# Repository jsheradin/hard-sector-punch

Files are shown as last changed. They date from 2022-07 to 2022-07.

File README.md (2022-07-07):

# hard-sector-punch

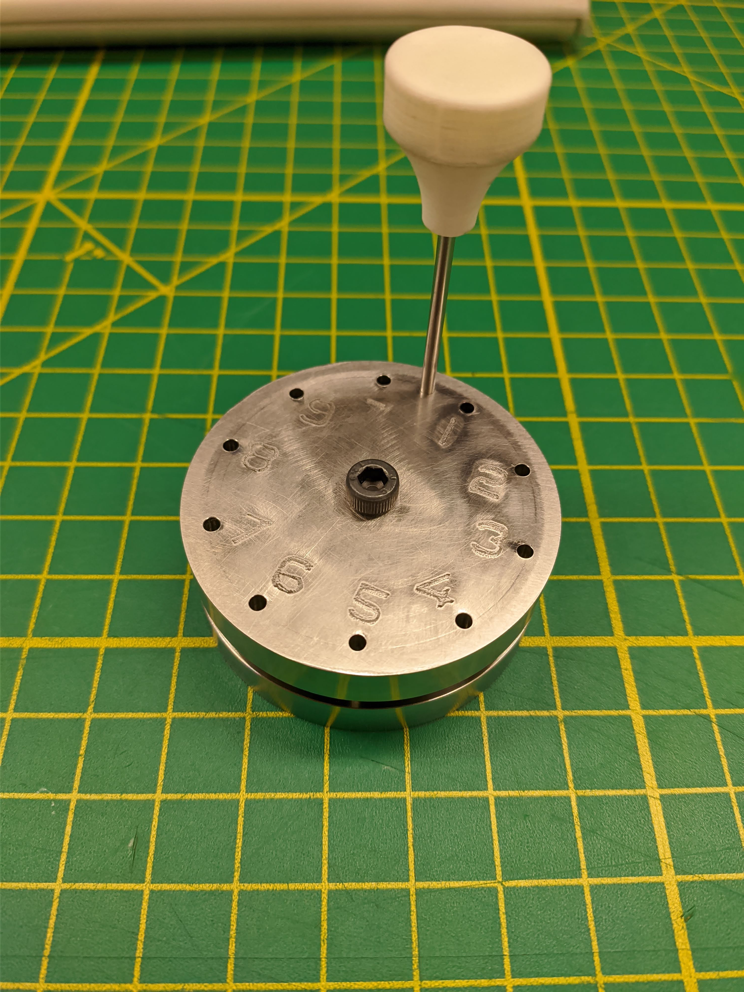
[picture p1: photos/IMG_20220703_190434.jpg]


## Purpose
Some older computers require hard-sector floppies. These differ from the more common soft-sector floppies in that there are additional holes to physically mark the beginning of each sector. Both soft-sector and hard-sector floppies have a hole to mark the start of rotation. Soft-sector floppies can be converted to hard-sector by punching the additional required holes.

## Floppy considerations
### Floppy size
Hard-sector formats were used in both 5.25" and 8" formats. The punches here are designed for use with 5.25" disks. I don't have any 8" disks on hand to check alignment.

### Coercivity
Most drives that used hard sector expect 300 Oe coercivity and won't be able to magnetize disks with higher coercivity. High-density (HD) floppies will most likely not work. The older double-density (DD) floppies likely will.

### Sector count
Not all hard-sector floppies are the same sector count. Usually a computer is only compatible with a specific configuration. 10 and 16 sectors were both commonly used in 5.25" format. 8" disks often had even more. The correct punch must be used to match the target machine.

### Single/double sided
Double-sided (DS) floppies will work for both double and single-sided drives. Single-sided (SS) floppies will work only in single-sided drives.

## Files
Provided are CAD files in various formats for a 10 sector 5.25" punch. They have been tested to work both as 3D printed PLA and CNC'd stainless steel. These were designed in Autodesk Inventor which uses ipt files. The exported stp files should be compatible with nearly all programs.

## Reaming
It's recommended to ream the punch holes to ensure as close of a fit as possible to the punch pin. McMaster #8803A208 reamer worked fine for both stainless steel and PLA. Use lots of oil/water respectively to keep things cool. Make sure both parts are aligned and tightened together when reaming. This will help ensure the holes are perfectly aligned between the top/bottom tools.

## Punch pins
McMaster #3023A353 and #98378A801 should both work fine. The latter will have a tighter fit providing cleaner punches; a knob file is also included for it. It makes punching easier if a V notch is carved into the tip of the punch pin. A diamond file works well for this.

## How to use
* Insert the punch pin through the index hole
* Line up the index hole on the floppy with the hole in the envelope
* Slide floppy onto tool
* Clamp opposite side of tool together using an M5 bolt
* Remove punch pin and rotate the sleeve so the hole in the sleeve is aligned with the hole to punch
* Firmly press punch pin through the tool and remove
* Repeat the rotate/punch steps for all sector holes
* Unbolt tool halves and inspect floppy for cleanly punched holes

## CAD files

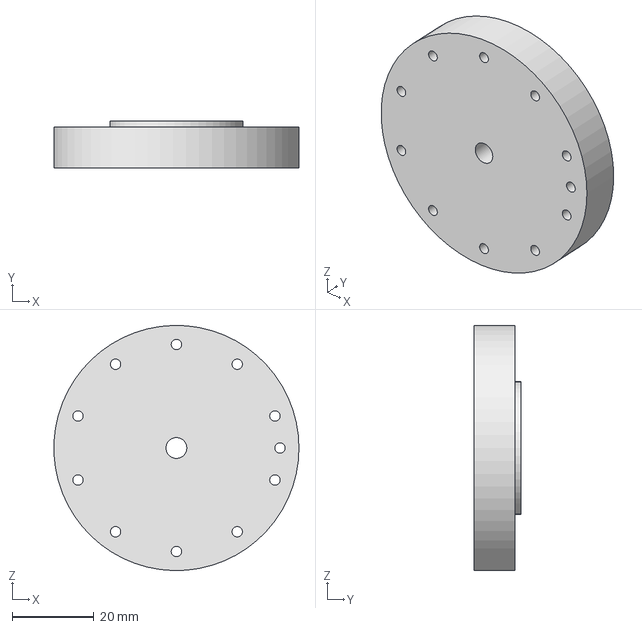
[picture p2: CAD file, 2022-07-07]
models/main_tool/top_v1.stp
60.0 x 11.5 x 60.0 mm

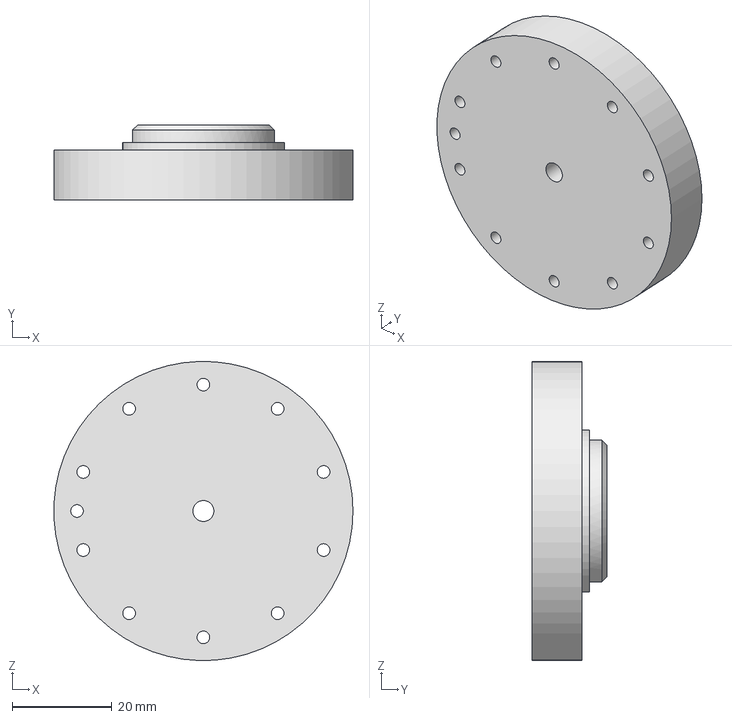
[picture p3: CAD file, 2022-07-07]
models/main_tool/bottom_v1.stp
60.0 x 15.0 x 60.0 mm

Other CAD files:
models/main_tool/bottom.ipt
models/main_tool/top.ipt
models/pin_knob/knob_bottom.ipt
models/pin_knob/knob_top.ipt

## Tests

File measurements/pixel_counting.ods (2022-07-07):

Conversion | 0.0211059518784297 | mm/px
Scale | px | mm
Y1 | 123
Y2 | 4861
Distance |  | 100
Drive hole
X1 | 2362 | 49.852258336851
X2 | 3710 | 78.3030814689742
Y1 | 2299 | 48.5225833685099
Y2 | 3651 | 77.0578303081469
Center X | 3036 | 64.0776699029126
Center Y | 2975 | 62.7902068383284
Diameter X | 1348 | 28.4508231321233
Diameter Y | 1352 | 28.535246939637
Diameter avg | 1350 | 28.4930350358801
Index hole
X1 | 1775 | 37.4630645842127
X2 | 1896 | 40.0168847615027
Y1 | 2912 | 61.4605318699873
Y2 | 3035 | 64.0565639510342
Center X | 1835.5 | 38.7399746728577
Center Y | 2973.5 | 62.7585479105108
Diameter X | 121 | 2.55382017729
Diameter Y | 123 | 2.59603208104686
Diameter avg | 122 | 2.57492612916843
Center dist. X | 1200.5 | 25.3376952300549
Center dist. Y | 1.5 | 0.0316589278176446
Center dist. | 1200.50093710917 | 25.337715008636
